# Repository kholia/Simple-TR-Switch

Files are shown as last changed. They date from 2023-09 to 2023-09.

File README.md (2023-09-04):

### Simple-TR-Switch

This is a non-RF-sensing, MCU PTT-controlled `Simple T/R Switch` with RX
Grounding feature which can be built for less than 2 dollars!

It was designed, and tested for https://github.com/kholia/Easy-Transceiver project.

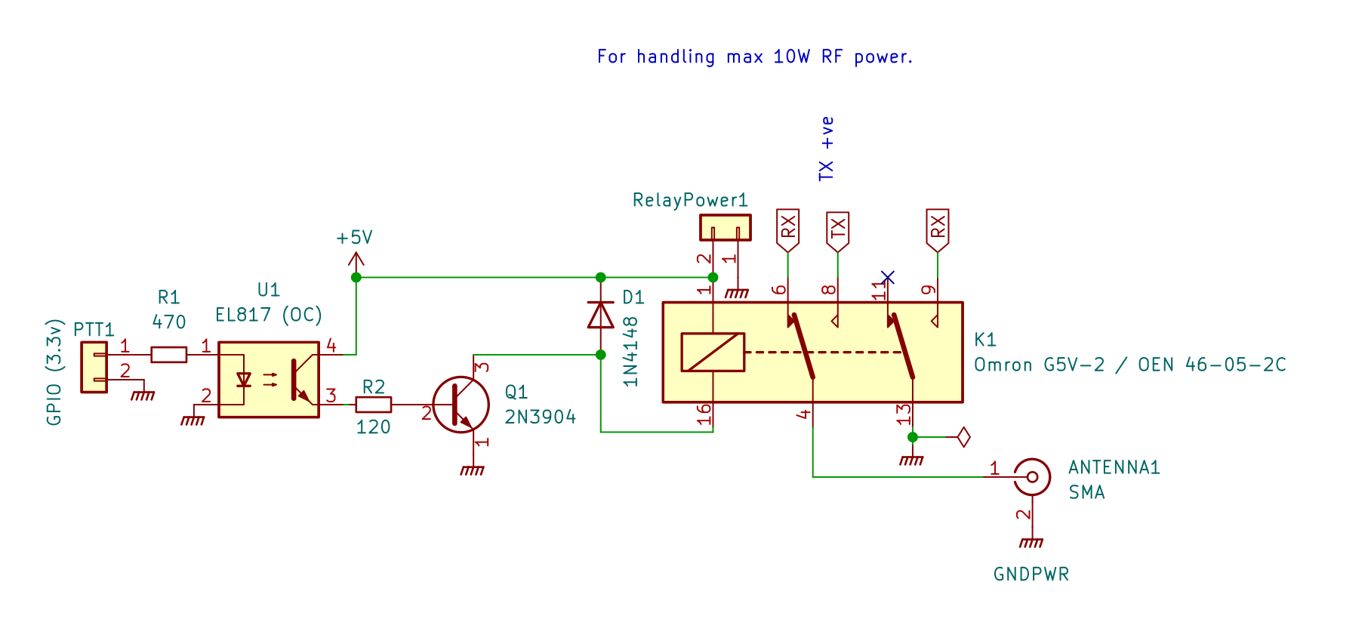
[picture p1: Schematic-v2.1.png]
Schematic

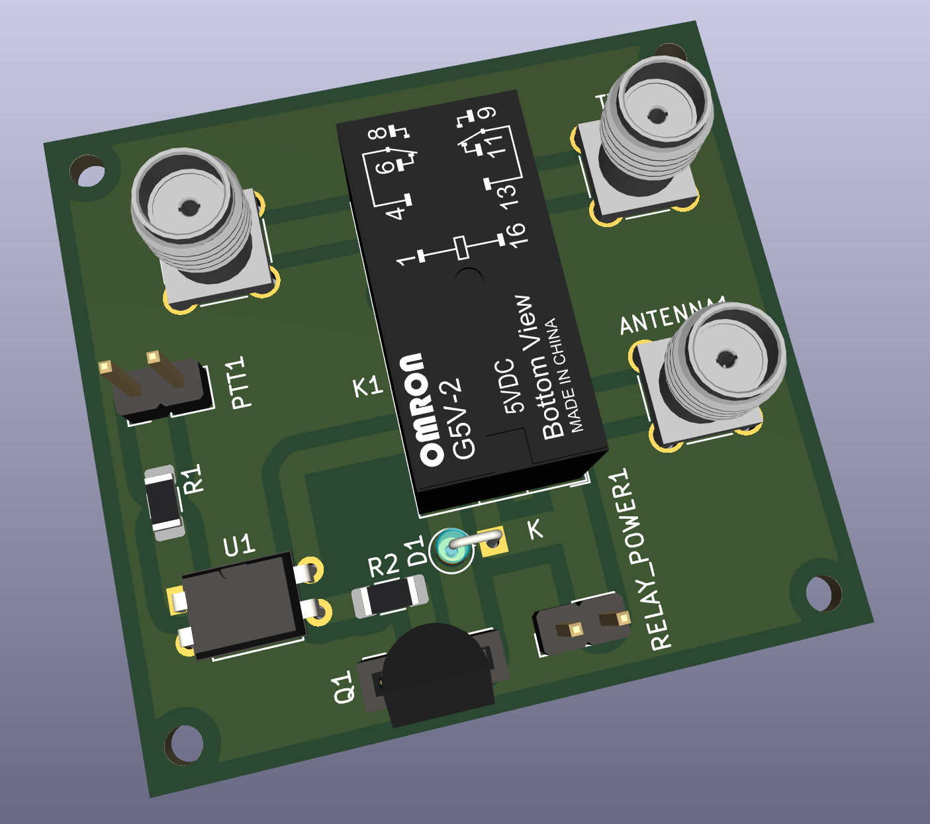
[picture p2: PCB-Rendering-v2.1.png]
PCB Rendering v2


#### Various approaches

TX power is 10W from IC-705 operating in FM mode.

- With a 2-channel relay as a T/R switch, when both RX Ground and Center are
  disconnected and left floating, a voltage of around ~2.2v is induced across
  RX connections which is unsafe for typical SDRs.

  ~2.2 Vpp is 10.93 dBm!

  https://www.random-science-tools.com/electronics/dBm-Watts-volts.htm

- With a 1-channel relay as a T/R switch which is switching the `Center`
  connection only, and with all Grounds (TX, RX, Antenna) shorted, a voltage of
  around ~1.66v is induced across RX connections which is theoretically safe
  for common SDRs.

- With a 2-channel relay as a T/R switch, with all Grounds (TX, RX, Antenna)
  shorted, with `Center` switching using Channel 1, and RX Center Grounding
  using Channel 2 during TX, a voltage of around ~500mV is induced across RX
  connections which should be fine for most common SDRs.

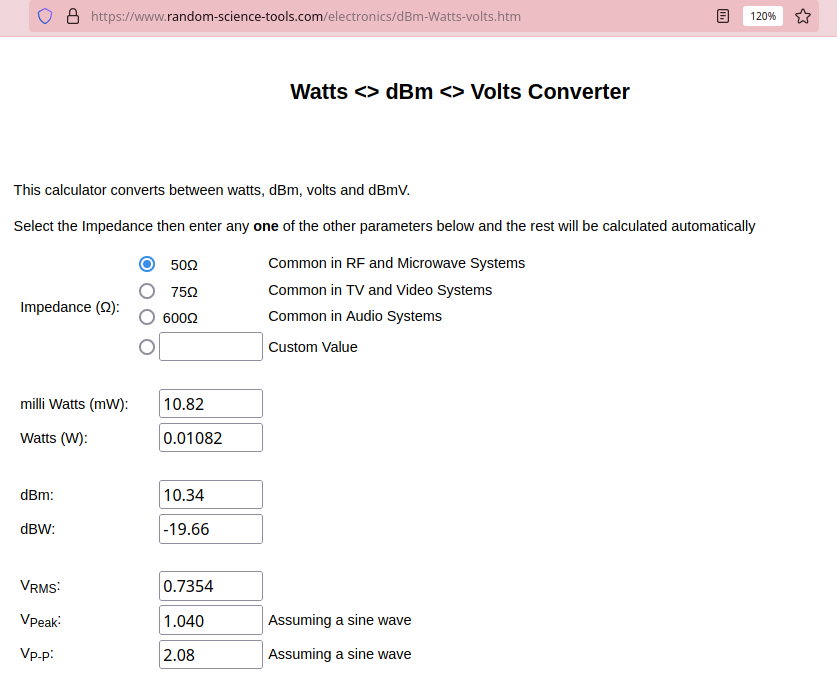
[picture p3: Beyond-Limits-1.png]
Beyond Limits


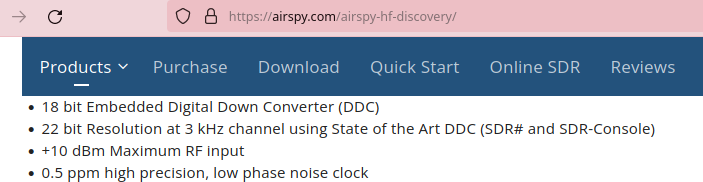
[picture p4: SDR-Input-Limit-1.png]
SDRs are sensitive devices


#### Comparisons

No external 12v power is needed unlike `Easy TR Switch` from https://www.qrpkits.com/ezseries.html.

The ~4000 INR `SDR Transceiver and Receiver Switch Antenna Sharer TR Switch Box
160 MHz` from Banggood doesn't work in `Automatic Mode` if there is
`Broadcast/SW Interference` in your area. The Banggood TR switch switches on
the RTX (red) and disconnects the SDR (RX) as soon as the antenna is connected
under `BCI` conditions, when operating in `Automatic Mode`.

#### BOM

- 5V 2A DPDT OEN MICRO RELAY 46-05-2C

  - https://etstore.in/index.php/product/oen-micro-relay-5v-dpdt-46-05-2c/
  - https://www.tomsonelectronics.com/products/oen-signal-relay-5v-dpdt

#### Added Protection

Here is another additional mechanism to protect sensitive SDRs.

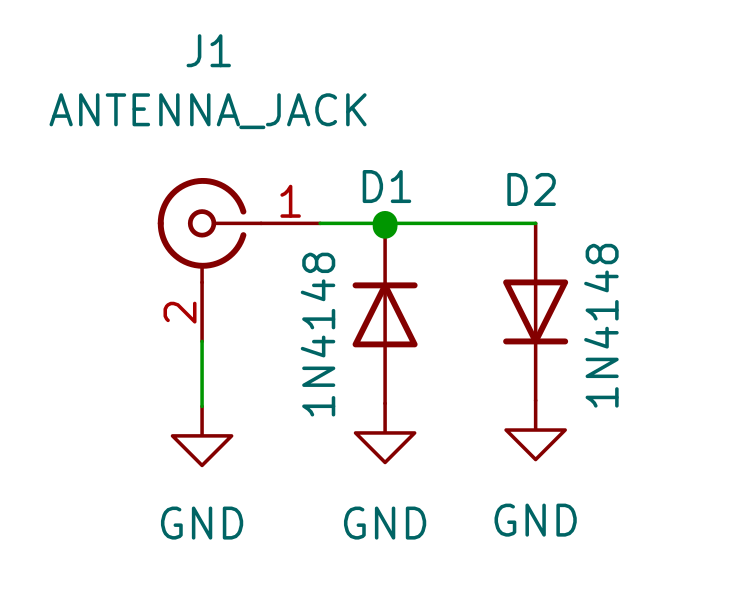
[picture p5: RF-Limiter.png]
RF Limiter


This is OK for HF (shortwave).

#### Alternate (but riskier) Option

Solid switching using BS170 could be another option.

The [info](./info) folder has more information on this.

#### Credits

Thanks to VU2ASH (Ashok Joshi), K.P.S. Kang, and LW1ECP (Daniel Alonso) for all
the help.

https://circuits-diy.com/optocoupler-relay-driver-with-pc817-2n3904/

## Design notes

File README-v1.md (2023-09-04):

### Simple-TR-Switch

This is a non-RF-sensing, MCU controlled `Simple T/R Switch` with RX Grounding
feature which can be built for less than 2 dollars!

It was designed, and tested for https://github.com/kholia/Easy-Transceiver project.

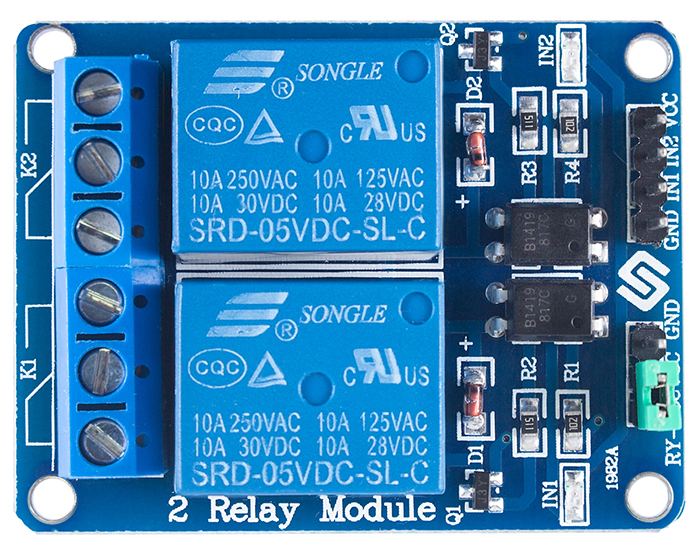
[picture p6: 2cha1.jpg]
Relay Module Looks

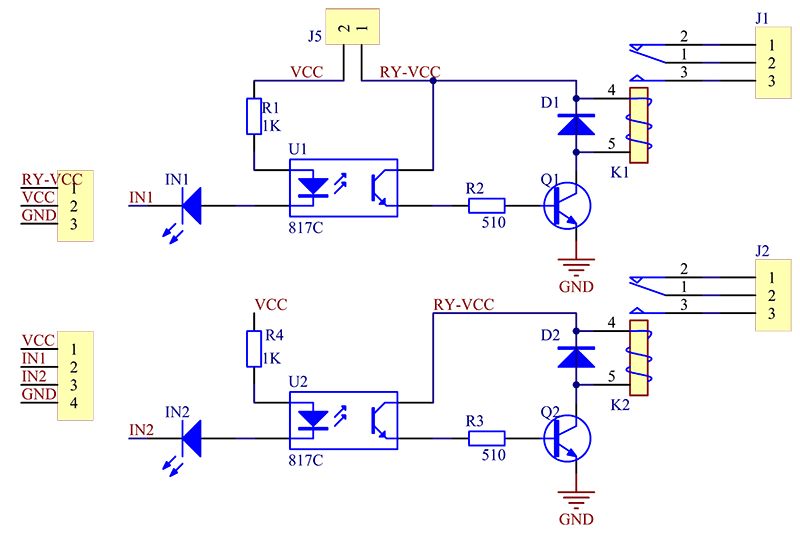
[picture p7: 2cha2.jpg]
Relay Module Schematic


#### Various approaches

TX power is 10W from IC-705 operating in FM mode.

- With a 2-channel relay as a T/R switch, when both RX Ground and Center are
  disconnected and left floating, a voltage of around ~2.2v is induced across
  RX connections which is unsafe for typical SDRs.

  ~2.2 Vpp is 10.93 dBm!

  https://www.random-science-tools.com/electronics/dBm-Watts-volts.htm

- With a 1-channel relay as a T/R switch which is switching the `Center`
  connection only, and with all Grounds (TX, RX, Antenna) shorted, a voltage of
  around ~1.66v is induced across RX connections which is theoretically safe
  for common SDRs.

- With a 2-channel relay as a T/R switch, with all Grounds (TX, RX, Antenna)
  shorted, with `Center` switching using Channel 1, and RX Center Grounding
  using Channel 2 during TX, a voltage of around ~500mV is induced across RX
  connections which should be fine for most common SDRs.

Beyond Limits

SDRs are sensitive devices

#### Comparisons

No external 12v power is needed unlike `Easy TR Switch` from https://www.qrpkits.com/ezseries.html.

The ~4000 INR `SDR Transceiver and Receiver Switch Antenna Sharer TR Switch Box
160 MHz` from Banggood doesn't work in `Automatic Mode` if there is
`Broadcast/SW Interference` in your area. The Banggood TR switch switches on
the RTX (red) and disconnects the SDR (RX) as soon as the antenna is connected
under `BCI` conditions, when operating in `Automatic Mode`.

#### Relay Connections

We use a 2-channel relay as a `T/R switch`.

Short all Grounds (TX, RX, Antenna).

```
Channel 1 (In 1):

- COM -> Antenna +ve
- NC -> RX +ve
- NO -> TX +ve
```

```
Channel 2 (In 2)

- COM -> Ground
- NC -> Not Connected
- NO -> RX +ve
```

In TX mode, turn on (i.e. make `NO` active) both Channel 1 and Channel 2, and
you should be good to go!

The following is a rough-schematic, only to show the connections involved.
Please use the relay module in practice. The flyback diodes across the relay
coils are important.

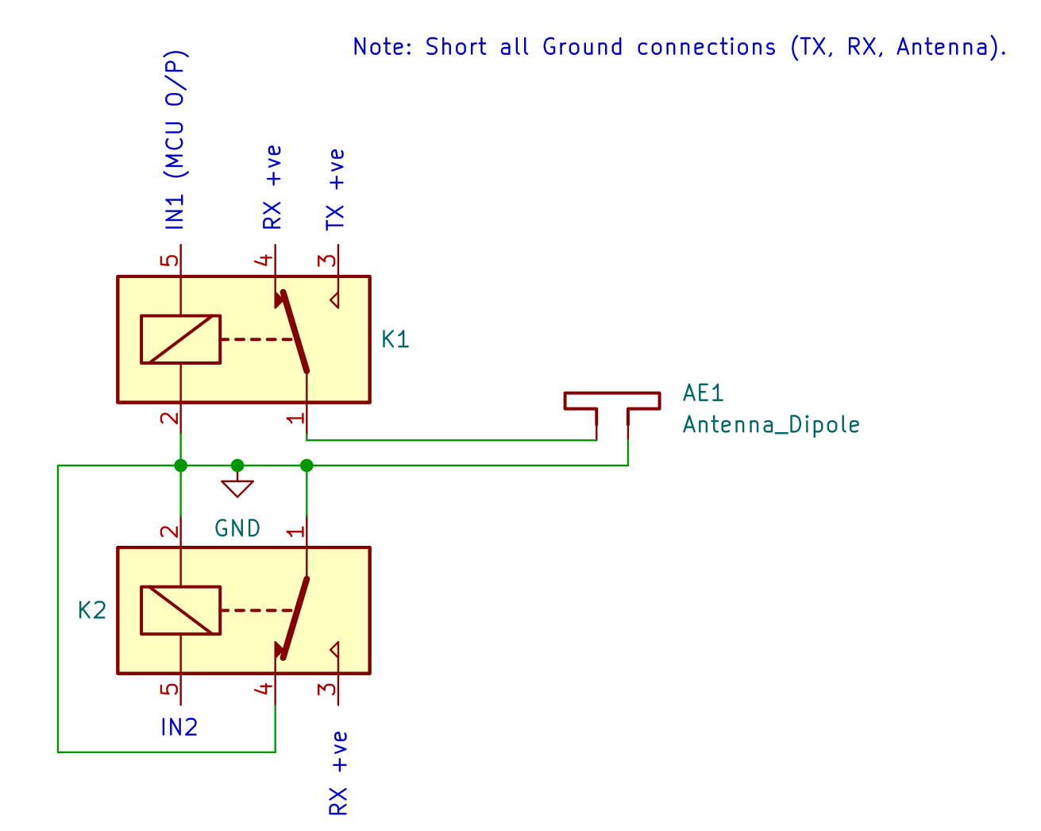
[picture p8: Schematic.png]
Schematic


#### Added Protection

Here is another additional mechanism to protect sensitive SDRs.

RF Limiter

This is OK for HF (shortwave).

#### Extender PCB

Use this for easy connections ;)

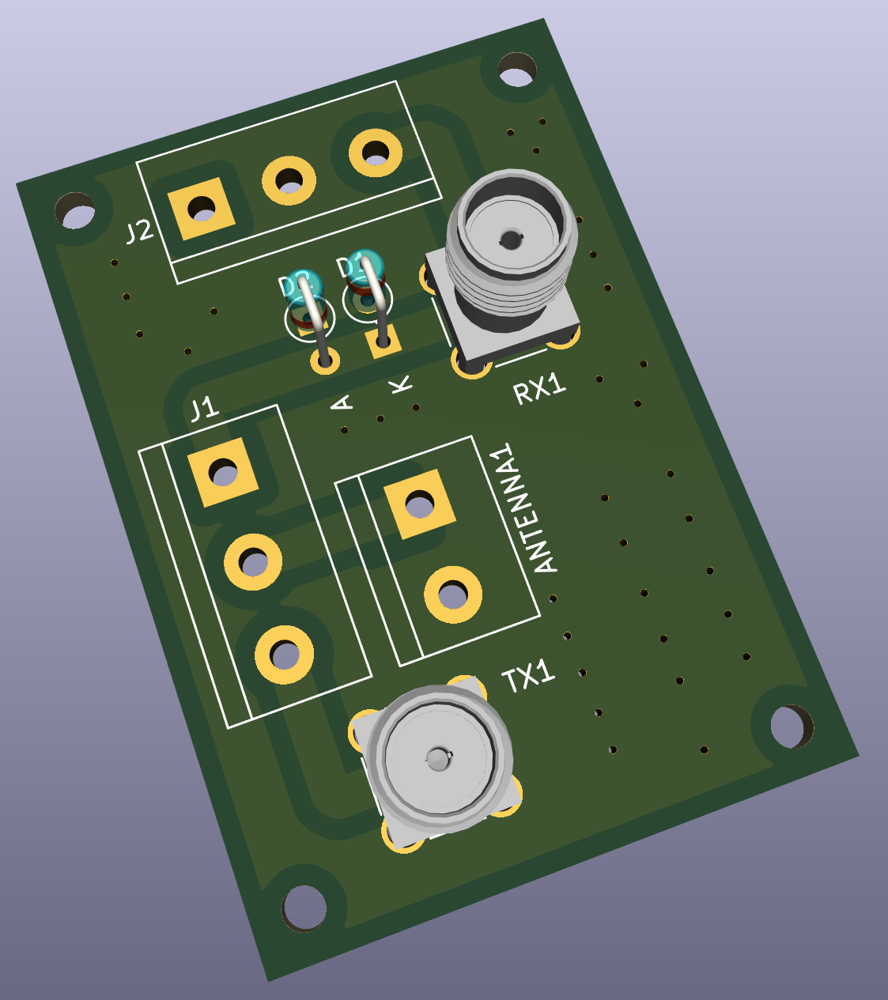
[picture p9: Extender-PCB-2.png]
Extender PCB


Use 0.5 sq. mm. wire with bootlace ferrules to ensure good contact. Keep the
wires short.

#### Alternate (but riskier) Option

Solid switching using BS170 could be another option.

The [info](./info) folder has more information on this.

#### Results (Feb-2022)

This TR switch affects SWR in the range of 0.10 to 0.15 for the worse, which is
quite acceptable in practice.

The TR switch is not affected by `BCI`.

After RX grounding, the RX line doesn't have any appreciable induced ("picked
up") voltage on it. The actual value couldn't be exactly determined due to
the measurement noise but it was less than 400mV as an rough approximation.
This was measured via an oscope using the differential probing technique
(`CH1 - CH2` in `MATH` mode).

The uSDX RX continued functioning just fine when connected to this TR switch,
after TX'ing 10W from IC-705 transceiver which was also connected to the same
TR switch.

#### BOM Sources

- https://www.electronicscomp.com/2-channel-5v-relay-module-with-optocoupler

#### References

- https://www.giangrandi.org/electronics/diode-clipper/diode-clipper.shtml

#### Credits

Thanks to VU2ASH (Ashok Joshi), K.P.S. Kang, and LW1ECP (Daniel Alonso) for all
the help.

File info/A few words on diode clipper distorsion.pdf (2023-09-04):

# A few words on diode clipper distorsion

## Introduction

I always had the habit of protecting the antenna input of many receiver circuits with a couple of back to back silicon diodes as visible in the picture below. This protects (within reason) a delicate circuit from unwanted strong signals applied to its input, such as switching on a nearby transmitter and having too much RF coupled to it or shorting to ground any static charge that may accumulate on an well insulated antenna. But I never spent time in investigating the additional distortion this circuit introduces, and this is the goal of this page.

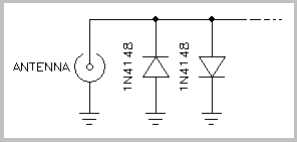
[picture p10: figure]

Typical antenna input circuit with protection diodes.

The basic idea of the diode clipper is that for signals with an amplitude within ±0.7 Vpeak (less than about +7 dBm over 50 Ω) the diodes are just open circuits and do not interfere; for higher amplitudes, the diodes clip the signal to about ±0.7 Vpeak limiting the maximum power that reaches the receiver at about
+10 dBm over 50 Ω, which the vast majority of receiver circuits can easily tolerate. If you wonder why I specified +7 dBm for unclipped signals and +10 dBm for clipped ones of the same peak to peak amplitude, it's because unclipped signals are supposed to have a nice sinusoidal shape; once clipped, they become more square and their RMS voltage is higher, explaining the 3 dB difference.

Now, this very simple diode model, where a diode is an open circuit for voltages below 0.7 V and clips at 0.7 V any higher level signal is just enough to estimate the limiting power, but is too simple to calculate the distortion on small (unclipped) signals. Diodes are non-linear devices often used in mixers and frequency multipliers, so they must introduce distortion. Now the question is: how much distortion? And is it acceptable?

## Circuit simulation

Now, the circuit that we want to simulate is basically a voltage divider with two diodes back to back as shown below:

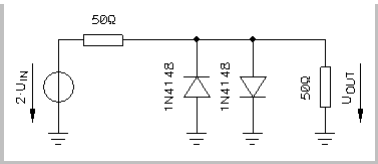
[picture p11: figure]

The circuit to simulate, the voltage source with its internal resistance is on the left, the two clipping diodes in the middle and the load is on the right.

The internal resistance of the generator (left) and the load resistance (right) are the two resistors of the divider. All impedances are supposed to be matched (both resistors are equal). The standard impedance of 50 Ω was selected because is the most common value for radio frequency circuits.

Very often, these two resistors are not "real" resistors, they are just how the source and load impedance look like, but they form indeed a voltage divider and the load voltage is half of the source voltage (when diodes don't clip). In practice, we don't have access to the true voltage source, and this 1:2 ratio is annoying. To avoid it, the source voltage is specified as 2·UIN, so that UIN is the voltage that appears on the load (UOUT) when no diodes are connected and we can compare what happens with and without the diodes without bothering with the 1:2 ratio.

The first attempt to simulate this circuit was done with a free SPICE simulator software, but rounding errors were too high for calculating any harmonic distortion or third order intercept point: it generated a strange and unrealistic noise floor
60 dB below the main signal. So a different way of simulation had to be found.

Finally, since the circuit is quite simple, I decided to directly calculate the output voltage in the old "pencil and paper" way. But for this, a good diode model is required.

The Shockley ideal diode equation is used here because it allows calculating precisely what happens for small and large signals. It relates the diode (forward) current ID as a function of diode (forward) voltage U.

It's an exponential function and depends on U, but also on three parameters that we consider constant for this simulation. The reverse bias saturation current IS and the emission coefficient n depend on the particular diode we want to simulate. Here, to simulate the famous 1N4148, we chose IS = 4.352 nA and n = 1.906 (these values are the ones specified by NXP in their SPICE model). Here we used a thermal voltage UT = 26 mV corresponding to a (room) temperature of 300 K and taken as constant. Small thermal variations are out of scope for this discussion.

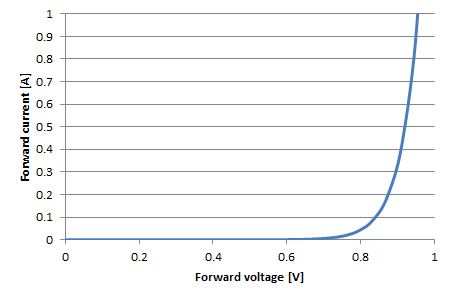
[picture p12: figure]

Diode forward current as a function of diode forward voltage of a 1N4148 according to the Shockley equation.

If we plot this equation, we get the above curve: it corresponds well to what we expect from a general purpose silicon diode such as the 1N4148.

The circuit to calculate can is completely described by the following two equations that are just the application of Kirchhoff laws:

;

ID(UOUT) is, of course, the Shockley equation described before. By combining and rearranging these two equations, we obtain the following:

Now, the above equation gives UIN(UOUT) while we are looking for UOUT(UIN). But solving for UOUT cannot be done analytically because of the exponential in the Shockley equation (or, if it can, I couldn't do it). So, I ended up in solving it numerically, using MS Excel, its numerical solver and some macros; it's not very elegant and is terribly slow, but finds a solution with the required accuracy and was readily available.

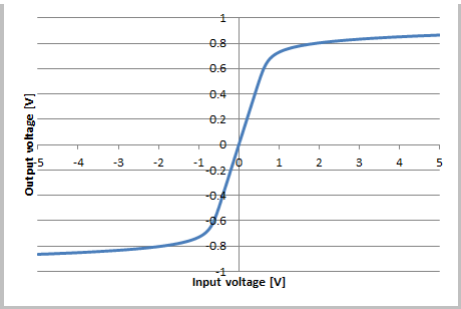
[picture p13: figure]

Transfer function of the diode clipper.

The calculated transfer function is visible in the above plot. As expected, it's about linear between ±0.6 V, for higher amplitudes se signal is compressed around ±0.7-0.8 V. This is a smooth curve and has no sharp angles.

Please remark that in this simulation, only the forward polarized diode is taken into account. The other diode is supposed to conduct no current: this greatly simplifies the calculation.

## Determining harmonics

Now that we have a nice model for the diode clipper, we can feed it with some sinusoidal input signal to calculate with good accuracy the clamped signal at the output. Then, with an FFT, we can precisely analyze the harmonic content of the output signal. By repeating this process for different amplitudes, it is possible to have an idea of the maximum signal that will go through the clipper undistorted (or with an acceptable distortion).

Several amplitudes have been used for this simulation: –100 dBm, –80 dBm,
–60 dBm, –50 dBm, –40 dBm, –30 dBm, –20 dBm, –10 dBm, –5 dBm, 0 dBm,
+5 dBm, +10 dBm, +15 dBm, +20 dBm, +25 dBm and +30 dBm. The typical signals that can be found on a receiver antenna connector range from –140 dBm to –30 dBm, –73 dBm being the standard S9 signal, (https://www.giangrandi.org/electronics/radio/smeter.shtml) already considered strong. There is no need to simulate signals weaker than –100 dBm because already at –100 dBm distortion is so low that cannot be calculated. On the other hand, signals up to
+30 dBm have been simulated to see what happens when the clipper really does its job.

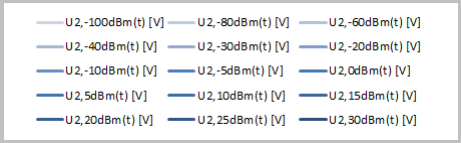
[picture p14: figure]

Legend for the signals plotted in the following two figures.

In the figure below, all input signals are displayed. With a linear scale, only the strongest ones are clearly visible.

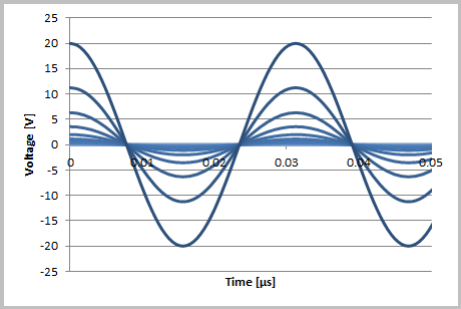
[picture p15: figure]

Input signals ranging from –100 dBm to +30 dBm.

The figure below shows how the signals look like after the clipper. Again plotted on a linear scale, the compression is clearly visible: the strongest signals (that exceeded several Volts before the clipper) are now within ±1 V and have a "square wave" appearance, while the weak signals go through undistorted and keep their sinusoidal shape.

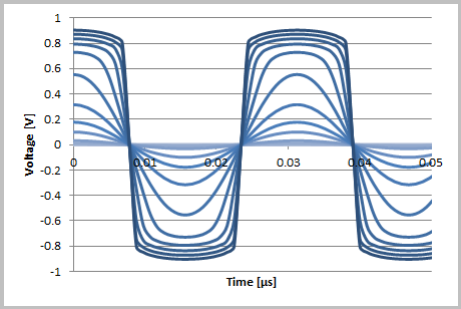
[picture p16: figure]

The same signals as in the previous image after clipping.

To perform reliable FFT on this numerical model, a few tricks are necessary: first, the FFT algorithm works only with a sampling period containing a number of samples which is an integer power or 2; here we used 1024 samples (= 2¹⁰). Than the signal to analyze must have an integer number of cycles in the sampling period, otherwise spurious signals will appear, polluting the result. Since the model is not frequency dependent, we arbitrarily chosen a sampling frequency of 1024 MHz, a sampling period of 1 μs (1024 samples, one every 0.977 ns), and a test signal of

32 MHz. With these conditions, it has exactly 32 full cycles in the 1024 samples. This gives an FFT resolution of 1 MHz, which is also handy.

Again, the simulation is calculated with MS Excel, its built in FFT function and some macros. As before, not elegant and slow but provides accurate results.

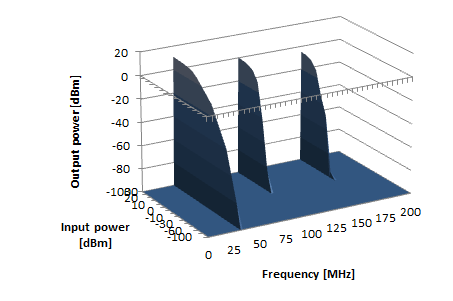
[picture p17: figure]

Waterfall plot of the FFT analysis of the diode clipper using a 32 MHz signal.

The result of the FFT is displayed in the above 3D plot. As one can see, for input signals below 0 dBm, the harmonic content is very low, but for stronger signals distortion rapidly appears with stronger and stronger harmonics.

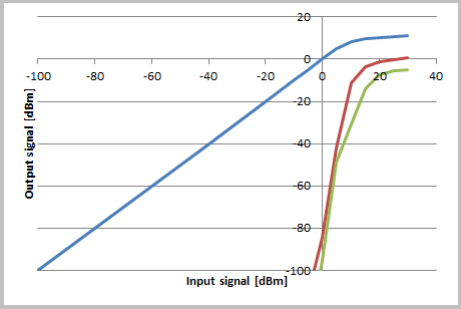
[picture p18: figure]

Frequency domain transfer function of the diode clipper. Blue: fundamental frequency, red: third harmonic, green: fifth harmonic.

Another way to look at it is in the frequency domain transfer function displayed above. We note that for low amplitudes, say below a few dBm, the clipper is linear and has a slope of 1 (the same signal goes through undisturbed). Distortion (harmonics) is almost non-existent in this region. At about 0 dBm third and fifth harmonics start to appear and grow very rapidly. At the same time, the transfer function shows a knee and even for strong input signals, the output does not exceed +10 dBm, as expected from a clipper.

## Determining IP3

Third order intercept point (IP3) is closely related (and very similar) to harmonic distortion. To evaluate its value the same analysis as before has been repeated using a superposition of two signals at two different frequencies, but with the same amplitude. The result has been analyzed in the same way. Since both signals must have an integer number of cycles in the 1024 samples, the frequencies of 16 and 24 MHz have been arbitrarily selected. They have respectively 16 and 24 cycles. Since the model is frequency independent, there is no reason to use frequencies very close to each other as one would use in a real life test.

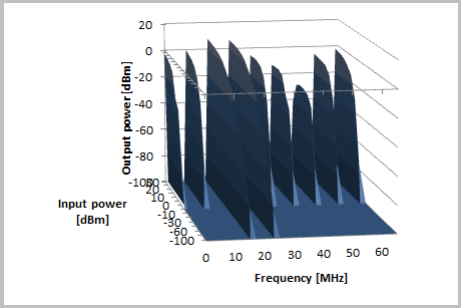
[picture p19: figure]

Waterfall plot of the FFT analysis of the diode clipper using two signals at 16 and 24 MHz.

The 3D waterfall graph (above) is now more crowded but very similar as before. One can easily see both input signals at 16 and 24 MHz and the third order intermodulation products appearing at 8 and 32 MHz for input signals stronger than about 0 dBm. Other higher order intermodulation products are visible as well.

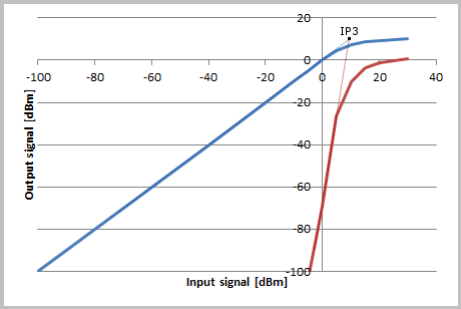
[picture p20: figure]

Frequency domain transfer function of the diode clipper. Blue: fundamental frequency, red: third order intermodulation products.

On the above frequency domain transfer function, the third order intercept point (IP3) is clearly visible and is at +10 dBm. Since the slope of the transfer function is 1 (same amplitude for input and output signals), there is no difference between input and output third order intercept points (IIP3 and OIP3 respectively): they both are +10 dBm.

## Some measurements

In order to verify what has been calculated before, some real measurements are a must. Here, a 1 MHz sinusoidal signal was used. Real life is not frequency independent and a "low" frequency such as 1 MHz allows neglecting the length of diode leads and the stray capacitance introduced by the diodes themselves. The two diodes are, of course, a pair of 1N4148. The result is shown in the waterfall plot below:

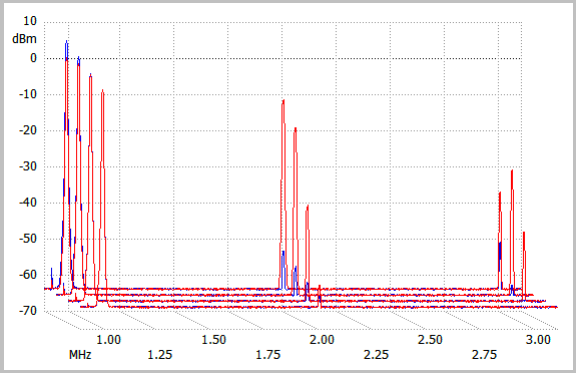
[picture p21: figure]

Measured spectra of a 1 MHz signal at four different amplitudes: +4 dBm, +1 dBm, –2 dBm and –5 dBm. Blue: no diodes, just the input signal. Red: diodes connected.

As one can see, for amplitudes below –5 dBm, no harmonics can be observed, but as the amplitude rises, as expected, harmonics appear and grow rapidly. This corresponds to the expectations.

But there are differences with the previous theoretical model: one is that in practice the input signal is not perfectly a pure sine wave and has already some harmonic content (blue traces). As expected, these harmonics are increased by the clipping action of the circuit.

Another difference is a strong presence of even harmonics, while in our theoretical model, only odd harmonics appear. I suspect that is due the two diodes not being identical and not clipping the signal symmetrically, but I didn't investigate this any further.

## Other considerations

One important question is: what is the maximum power that we can feed to the clipper without damaging it? According to the NXP datasheet, a 1N4148 diode can withstand a continuous DC current of 200 mA and can dissipate maximum of
500 mW. Let's first calculate what is the power dissipated by the diode at its maximum current: 200 mA · 0.7 V = 140 mW. Since this is lower than its maximum power rating of 500 mW, we will use 200 mA in our calculation, otherwise we would have to use a lower current. When the diodes are clipping, the load impedance is no longer 50 Ω because of the diodes somehow shorting it to ground. Since current in the diodes is much larger than the current in the load, we will neglect the latter and consider that all current is flowing through the diodes. When a power source delivers half of the diode maximum current on a 50 Ω load, here 100 mA, it delivers (100 mA)² · 50 Ω = 0.5 W of power. When the same source is connected to our clipper it will no longer be matched to 50 Ω because of the diodes appearing like a short circuit: the current will tend to double (our maximum
200 mA) and the power will drop significantly because voltage is now limited around 0.7 V. Therefore we can say that the maximum safe power source than we can connect is around 0.5 W (27 dBm).

Higher ratings diodes will certainly resist a higher power, but will probably have the disadvantage of introducing more stray capacitance. Each 1N4148 will add
4 pF: depending on the frequency this may or may not be a problem, and may require compensation. For example, if there is a low-pass filter after the clipper, is easy to compensate for the extra stray capacitance, just by reducing the parallel input capacitor.

Diodes often (but not always) show a nice feature: when too much power is applied, they will of course blow up; but after blowing up, they become a short circuit. In this case, even if the diodes are dead, they are still protecting the rest of the circuit. So, even if an overload does occur, there are still good chances that only two diodes of the clipper are faulty.

Not every diode is suitable for this circuit: fast diodes are needed. 1N4148 have a switching time of 4 ns and are good up to a few dozen MHz; for higher frequencies, faster diodes should be used.

## Conclusion

The effect of two back to back diodes in parallel with a receiver antenna connector has been analyzed. Their effect is negligible for weak signals, say below –20 dBm, it becomes observable around 0 dBm and the clipping action limits the maximum power around +10 dBm. The IP3 has been calculated to be +10 dBm.

If this is acceptable or not depends on the application. A diode clipper will certainly ruin the performance of a professional top of the line +30 dBm or more IP3 receiver, but can accepted in many other cases: when the receiver is just good but not a top performer, or when the antenna is located and designed in such a way that it doesn't pick up strong signals, or when a narrowband filter prevents strong signals to reach the clipper.

## Bibliography and further reading

[1] Dr. F. Rahali, Prof. M. Declercq. Électronique I, partie 2: dispositifs à semiconducteurs. École Polytechnique Fédérale de Lausanne, 1996, chapitre 8.
Home (https://www.giangrandi.org/index.shtml) | Electronics (https://www.giangrandi.org/electronics/electronics.shtml) | Page hits:
| | 017599

Created:
09.2014

Last update:
09.2014

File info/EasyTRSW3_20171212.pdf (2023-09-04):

# Pacific Antenna Easy TR Switch Kit

## Kit Description

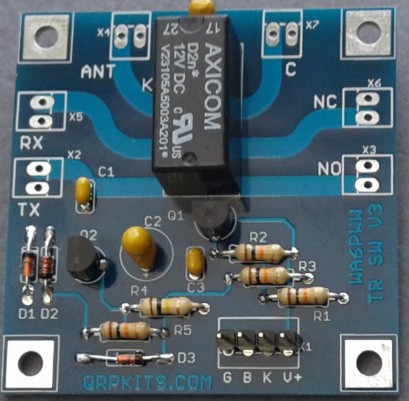
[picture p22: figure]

The Easy TR Switch is an RF sensing circuit with a double pole double throw relay that can be used to automatically switch an antenna between a separate receiver and transmitter.

It also has a second switched pair of inputs and outputs that can be used for other switching applications such as muting or switching an audio channel or even to switch a remote amplifier or pre-amplifier.

Manual operation is achieved through use of control inputs to disable RF switching and to key the relay.

## Features and Specifications

Provides automated or manual switching
Two independent sets of inputs and outputs
Automatic Rf sensing requiring as little as 50mW of RF for switching Frequency range of 160-6M
Power handling of up to 125 Watts
All on a 2 by 2 inch circuit board.

## Support

PACIFIC ANTENNA
QRP KITS.COM
qrpkits.com@gmail.com
Easy TR Switch V3 20171212 | 1

## Recommended Tools

□ Temperature Controlled Soldering Station with small tip or a 15-35 watt soldering iron with small tip. □ Solder 60/40 or 63/37 Tin-Lead
□ Small Diagonal Cutters
□ Small Needle Nose Pliers
□ Pencil, Pen, and/or Highlighter □ BRIGHT work light

## Optional

□ Magnifying headpiece or lighted magnifying glass. □ Multi-meter
□ Solder Sucker or Solder Wick
□ Knife or Wire Stripper
□ Cookie Sheet to build in and keep parts from jumping onto the floor.

## Construction Techniques

□ Please take time to inventory the parts before starting. Report any shortages to QRPKITS.com (In many cases it may be faster and cheaper to pull a replacement from your parts supply, but please let us know if we missed something.)

□ Pre-sorting the resistors and capacitors can speed up the assembly and reduce mistakes.

□ There is no need to print out the whole assembly manual unless you want a copy. Print the Parts List and Schematic (last two pages) then view the rest of the manual on a computer, laptop, or tablet. The Parts List has columns for inventory and construction.

□ You can insert several parts at a time onto the board. When you insert a part bend the leads over slightly to hold the part in place, then solder all at the same time. Clip the leads flush.

□ Most parts should be mounted as close to the board as possible. Transistors should be mounted about 1/8” above the board. Solder one lead on ICs or IC sockets and then check to make sure the component is flush before soldering the remaining leads.

□ Use a Temperature Controlled Soldering Station with small tip or 15-35 watt soldering iron with small tip. Conical or very small screw driver tips are best.

□ DO NOT use a large soldering iron or soldering gun.

□ If you are a beginner, new to soldering, there are a number of resources on the web to help you get on the right track soldering like a pro. Google Soldering Techniques.

Easy TR Switch V3 20171212 | 2

## TR Switch V3 Parts List

Qty Value | Component | Description
4 | 10K | R1, R2, R3, R5 | Resistor, 1/4W, Brown-Black-Orange-Gold
1 | 100K | R4 | Resistor, 1/4W, Brown-Black-Yellow-Gold
2 | 1N4148 | D1, D2 | Diode, glass body (Check labels with magnifier)
1 | 1N5240 | D3 | Zener diode, 10V, glass body, (Check label with magnifier)
1 | 47pF | C1 | Monolythic Capacitor, marked 47 or 470. (0.1” lead spacing)
1 | 22pF | C1 alternate | Monolythic Capacitor, marked 22 or 220. (0.1” lead spacing)
2 | 0.1uF | C3, C4 | Monolythic Capacitor, marked 104. (0.1” lead spacing)
1 | 4.7uF | C2 | Tantalum polarized capacitor, marked 4u7 or 475
1 | 2N3906 | Q1 | PNP Transistor
1 | BS170 | Q2 | N-Channel MosFet
1 | Relay | K1 | Axicom V23105 12V relay
1 | PCB | PCB | Circuit Board labeled TR SW V3

Typical Parts Appearance

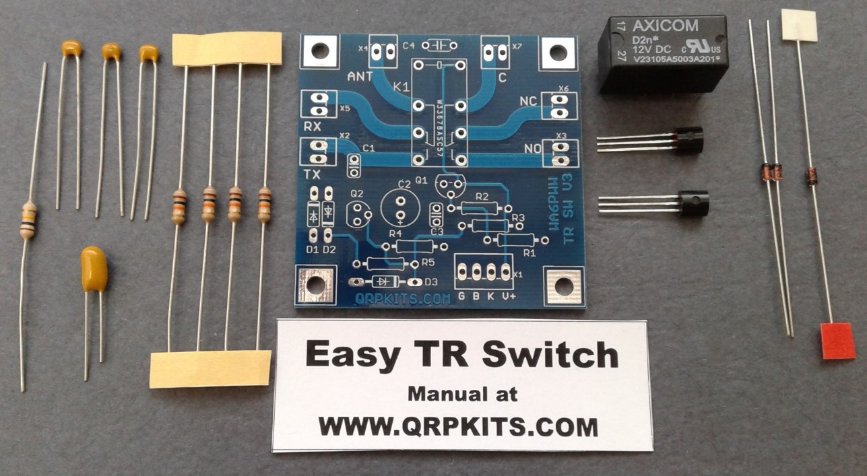
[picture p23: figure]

Note: Some parts may vary in appearance from those shown here due to source changes.

Easy TR Switch V3 20171212 | 3

Board Layout

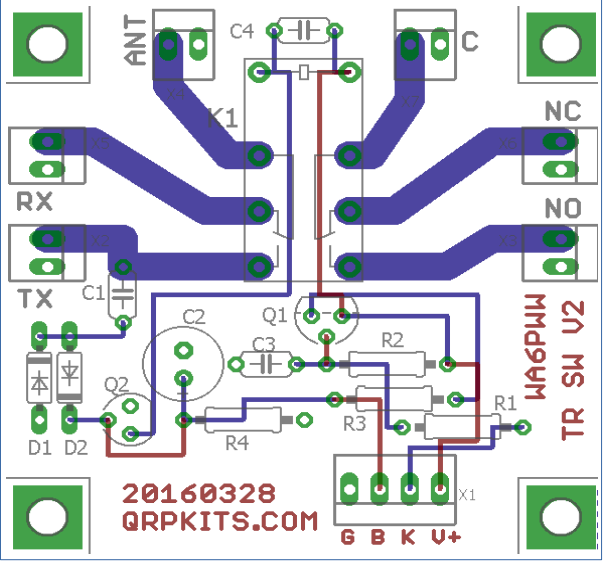
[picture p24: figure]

Note: Pin 1 of X1 is the pad closest to the X1 Label (on the right above) and is the connection point for 12V power. The leftmost pin (4) is ground connection.

Install the following components on the PC board.
Resistors
R1 | 10K Ohm, 1/4W, Brown-Black-Orange-Gold
R2 | 10K Ohm, 1/4W, Brown-Black-Orange-Gold
R3 | 10K Ohm, 1/4W, Brown-Black-Orange-Gold
R5 | 10K Ohm, 1/4W, Brown-Black-Orange-Gold
R4 | 100K Ohm, 1/4W, Brown-Black-Yellow-Gold

Capacitors
C1 | 47pF Note: a 22pF is also included and is recommended for high power (>50W) use.
C2 | 4.7uf Tantalum Note: align + side lead with + pad on board outline
C3 | 0.1uF monolythic ceramic, marked 104
C4 | 0.1uF monolythic ceramic, marked 104

Transistors and diodes
Q1 | 2N3906 (align flat to board outline with center pin away from flat)
Q2 | BS170 (align flat to board outline with center pin away from flat)
D1 | 1N4148 (align band to board outline) Note: confirm labels on diodes with magnifier
D2 | 1N4148 (align band to board outline) Note: confirm labels on diodes with magnifier
D3 | 1N5240 (align band to board outline), Note: confirm labels on diodes with magnifier

Misc parts
K1 | Axicom V23105 Relay, (only fits one way due to pin configuration)
Header | Pin header that can be used for connection if wires are not to be directly soldered
Easy TR Switch V3 20171212 | 4

## Operation

The TR switch provides switching between two separate sets of contacts to two separate output/input pairs.
It will sense RF input on the TX inputs and switch at approximately 50mW of RF and above and can be used over a frequency range of 160-6M and up to 125 Watts of RF under matched conditions.
The switch can be bypassed by grounding pin 3 (Bypass) of the control inputs (X1). This will prevent the switch from engaging either in manual or automatic, RF sensed mode.
For testing, or for manual switching from an external control, operation of the relay can be accomplished by grounding pin 2 (Key).
12V DC power should be connected at connector SV1 with V+ to pin 1 (marked “V+”) and ground to pin 4 (marked “G”)
Choice of C1:
Capacitor C1 senses the RF signal and feeds the signal to Q2 to control switching.
The 47pF capacitor supplied for C1 should work over most conditions and is recommended for most applications. An extra 22pF capacitor is also included and is recommended if power levels used will always be above 50W.
If automated switching is not reliable on certain frequencies, or at certain power levels, the value of C1 may need to be adjusted.
In general, increase C1 for lower frequency and/or lower power operation and decrease it for high frequency and or high power use.

## Board Connections

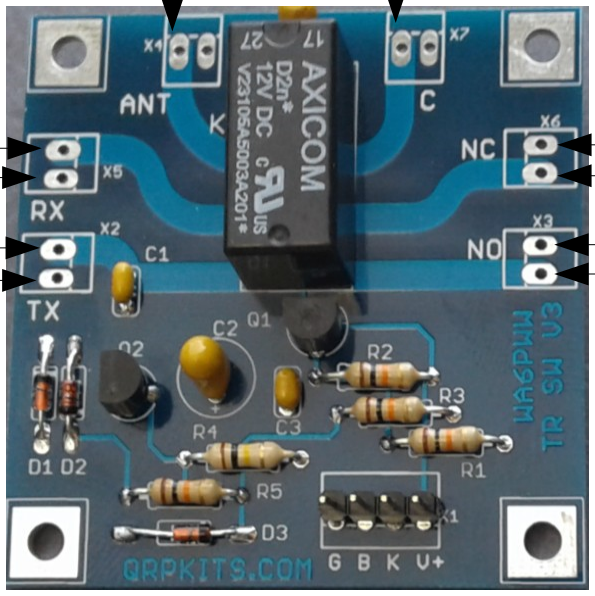
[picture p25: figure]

The Antenna, RX and TX as well as the second switched pair (C, NC and NO) are as shown above.

Easy TR Switch V3 20171212 | 5

RX
GND

TX
GND

GND
Normally Closed

GND
Normally Open
Antenna | Aux.

For the pads marked RX, TX, NC and NO, the connection is to the upper pad and the lower pads are connected to ground on the board as shown above.

For antenna switching between a receiver and Transmitter, you will only need to use the ANT, RX and TX connections.

The Auxiliary contact set can be utilized to mute audio of a receiver by switching its output to a resistor during transmit instead of the speaker or headphones.

This would be accomplished by connecting the audio to the Aux input and connecting a speaker to the normally closed (NC) output and a 10 ohm or so resistor from the normally open output to ground.

If the TR switch is embedded into another system, jumper wires can be used to the appropriate pads for signals, power and control lines (if needed).

To connect to a BNC or other external RF type connectors, the center will go to the pads as shown below and the ground is the adjacent pad.

You can see the pads with traces and connected to ground by looking at the back of the board. As a guide, the trace locations are shown in the drawing below.

The additional switched contacts (if used), are connected in the same manner.

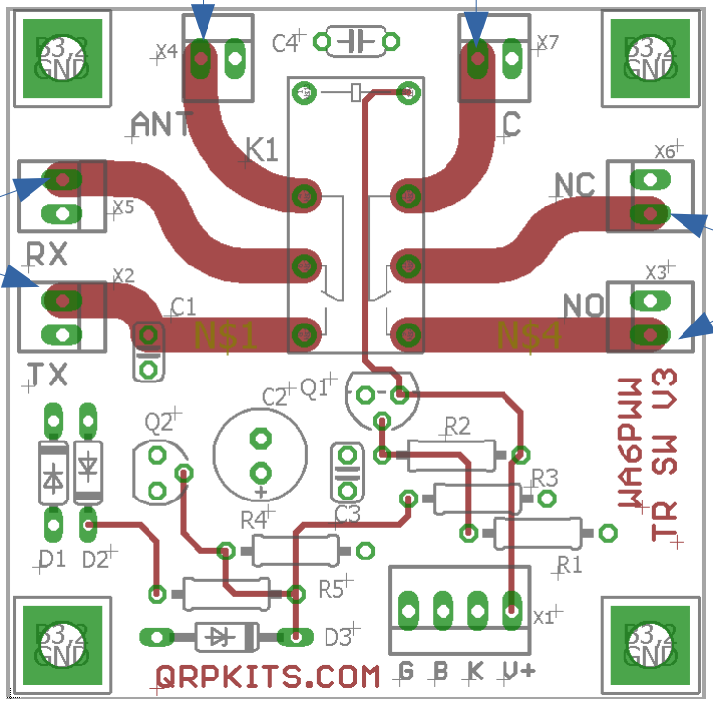
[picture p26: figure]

Easy TR Switch V3 20171212 | 6

Connect
center of
BNC here

Connect
center of
BNC here

Connect
center of
BNC here

Connect
center of
BNC here

X1: Control and Power input
Pin 1: V+; Pin next to X1 label on board, connects to a 12 Volt supply to power the TR switch. Pin 2: K; External keying control line. Ground this pin to key the TR switch manually.
Pin 3: B: Bypass control line. Ground to disable switching.
Pin 4: Ground for power, control and key signals

## Troubleshooting

The Easy TR switch is intended to be easy to assemble and should operate without any problems. However, if it fails to operate, there are a few things to check:

Check the board for cold solder joints, these will appear rough rather than shiny. If in doubt, reheat connections to ensure a good connection.

Check for any solder bridges or solder whiskers that may short between adjacent pads

Verify correct location and orientation of the diodes D1 and D2 as well as the transistors Q1 and Q2. They should be oriented as shown on the PC board outlines.

Verify that power and ground are connected to Pads 1 and 4 of X1.

Test by connecting Pad 2 of X1 to ground with 12 power applied to Pin 1. You should be able to hear the relay click. If not, recheck components and solder connections as indicated above.

When applying RF to the TX input, with an antenna or dummy load connected to the output you should hear the relay click.

Capacitor C1 is part of the RF sensing circuit that controls the automatic TR switching.

The kit is supplied with a 22pF capacitor for C1 and for most applications, this will work well. In general, a larger value capacitor (47 or 100pF) may improve switching at low power and low frequencies (<1Mhz).

If you still experience problems, or have any questions, please contact us at qrpkits.com@gmail.com and we will be happy to assist you.

Easy TR Switch V3 20171212 | 7
4 | 3 | 2 | 1
G | B | K V+

X1

## Schematic

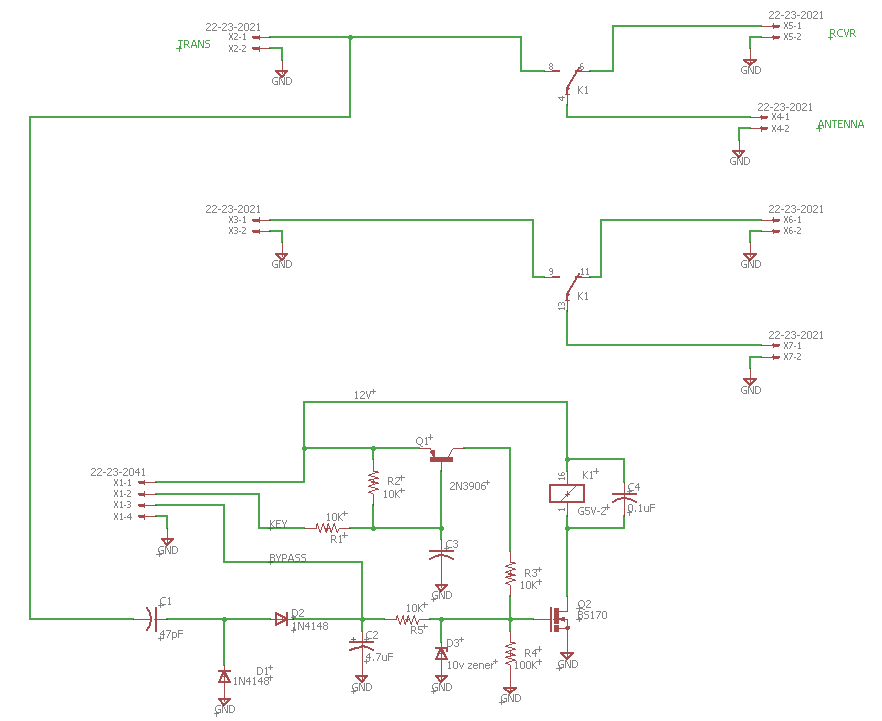
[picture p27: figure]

Easy TR Switch V3 20171212 | 8

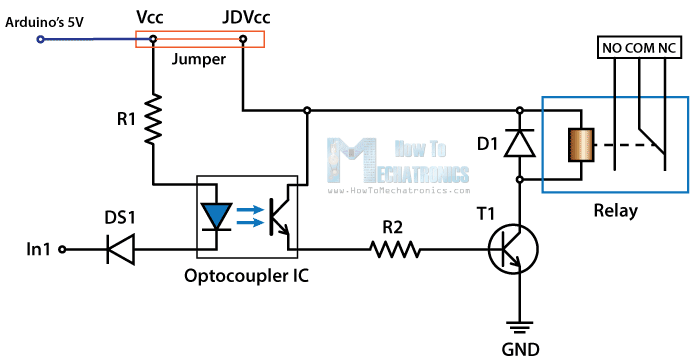
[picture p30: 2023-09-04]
info/HL-52S-Relay-Module-Circuit-Schematics.png

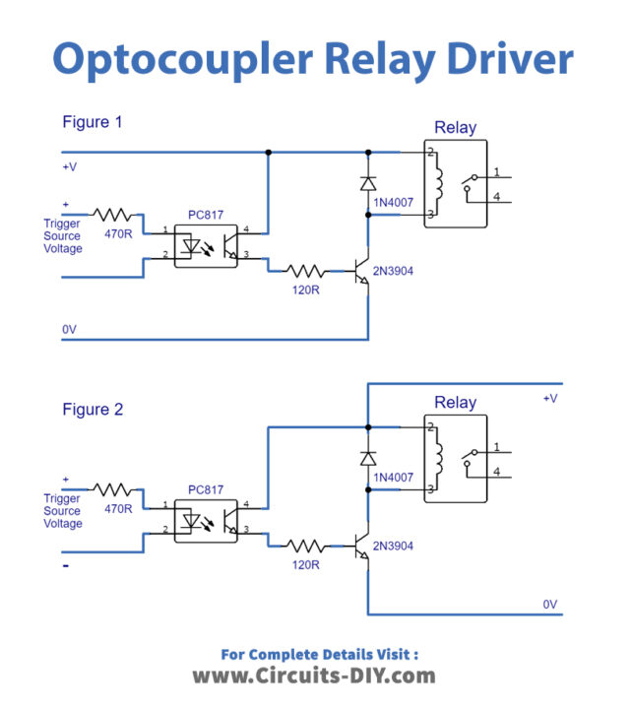
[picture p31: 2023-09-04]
info/Optocoupler-Relay-Driver-Circuit-Diagram-Schematic-641x720.jpg

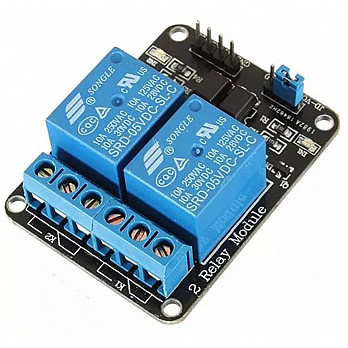
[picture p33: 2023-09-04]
dual-channel-relay.jpeg

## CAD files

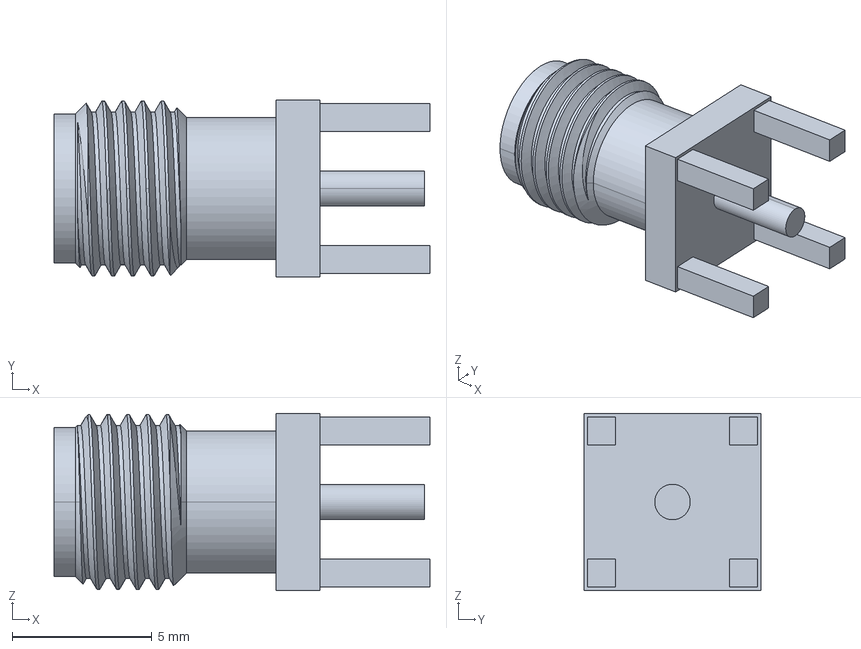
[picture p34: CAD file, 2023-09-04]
extender-pcb/models/901-144.stp
13.5 x 6.35 x 6.35 mm

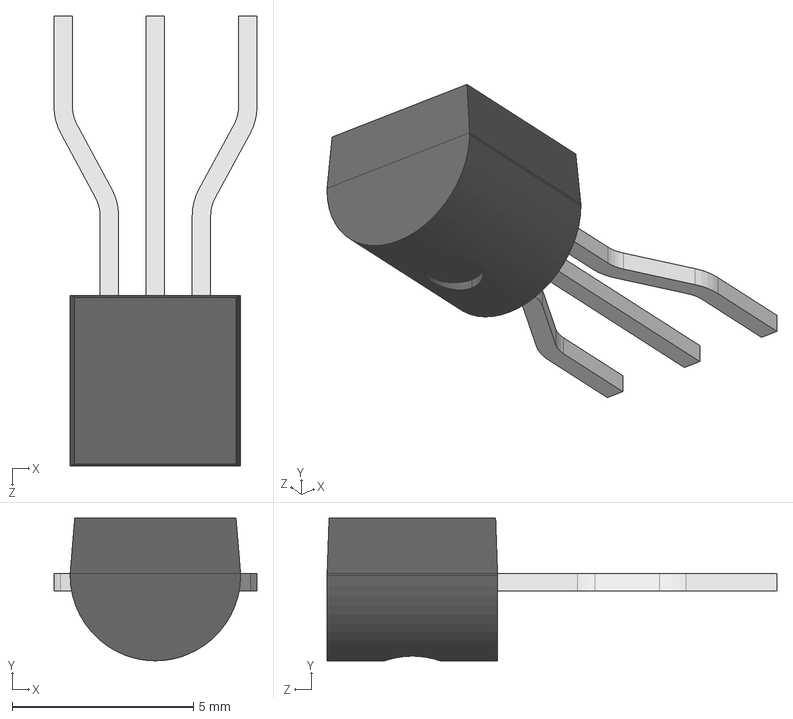
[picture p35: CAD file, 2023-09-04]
v3/models/User Library-TO-92-2_54-line.STEP
5.60 x 3.93 x 12.4 mm
User Library-TO-92 Version2_TO-92 Part1
User Library-TO-92 Version2_TO-92 Part3
User Library-TO-92 Version2_TO-92 Part4
User Library-TO-92 Version2_TO-92 Part5

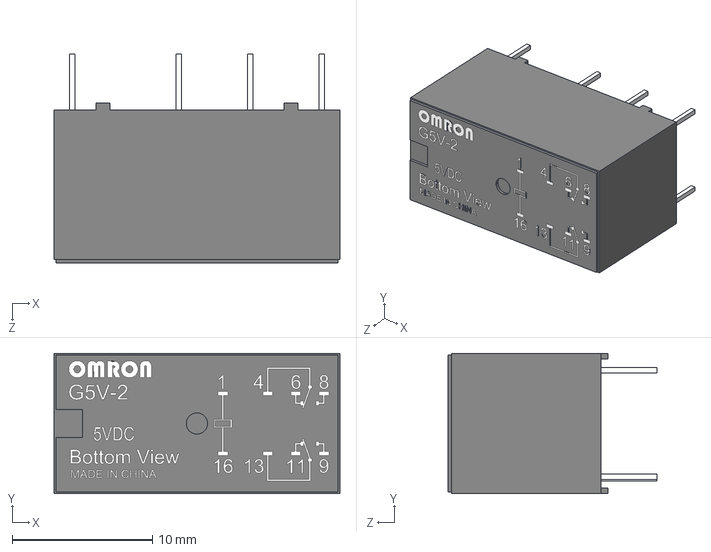
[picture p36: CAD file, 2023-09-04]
v3/models/User Library-OMRON G5V-2.STEP
20.4 x 10.0 x 14.9 mm

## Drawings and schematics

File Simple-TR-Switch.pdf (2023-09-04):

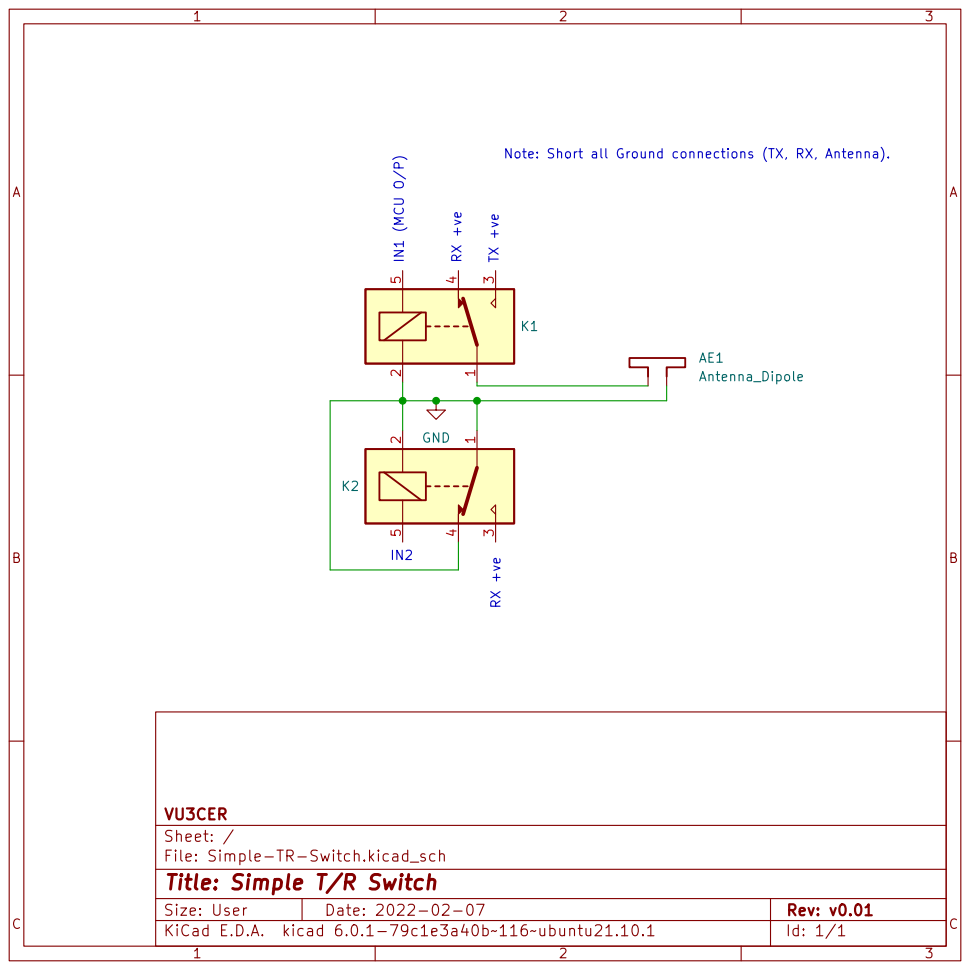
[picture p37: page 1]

3 K2 GND RX +ve TX +ve

File: Simple-TR-Switch.kicad_sch Sheet: / VU3CER

Id: 1/1 Title: Simple T/R Switch

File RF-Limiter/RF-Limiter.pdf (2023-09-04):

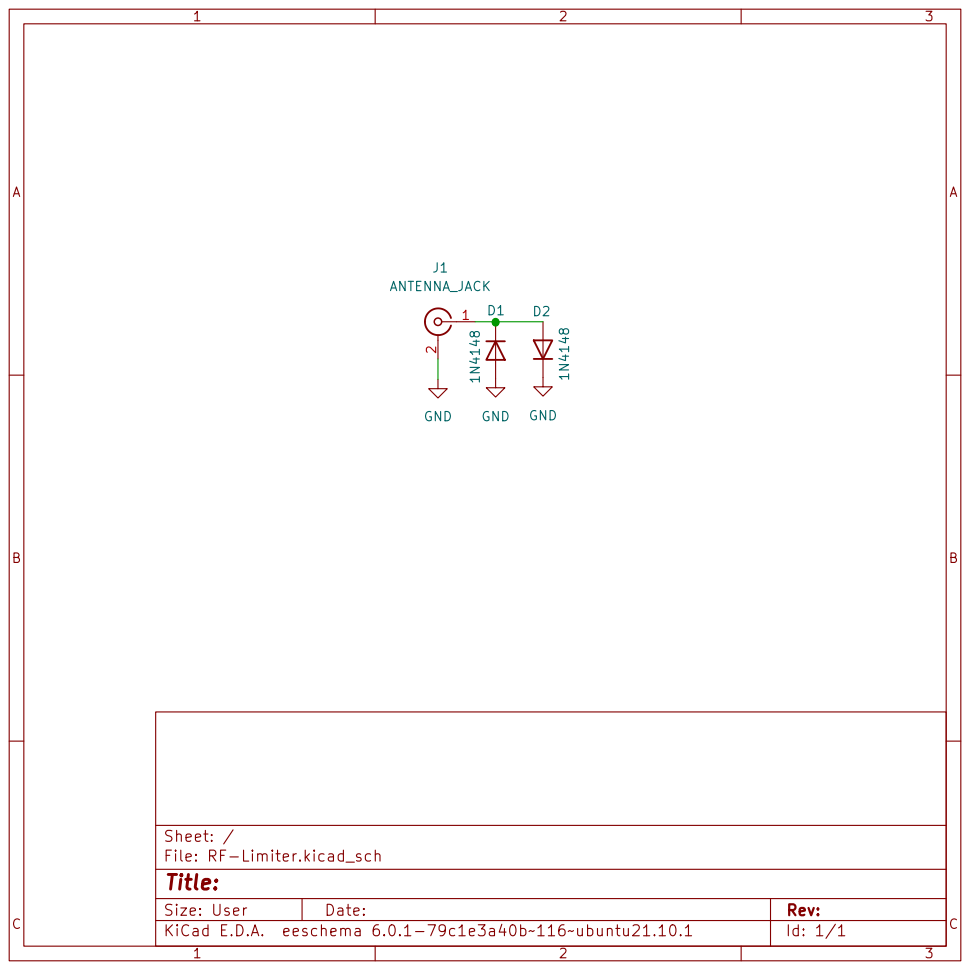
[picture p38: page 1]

File: RF-Limiter.kicad_sch Sheet: /

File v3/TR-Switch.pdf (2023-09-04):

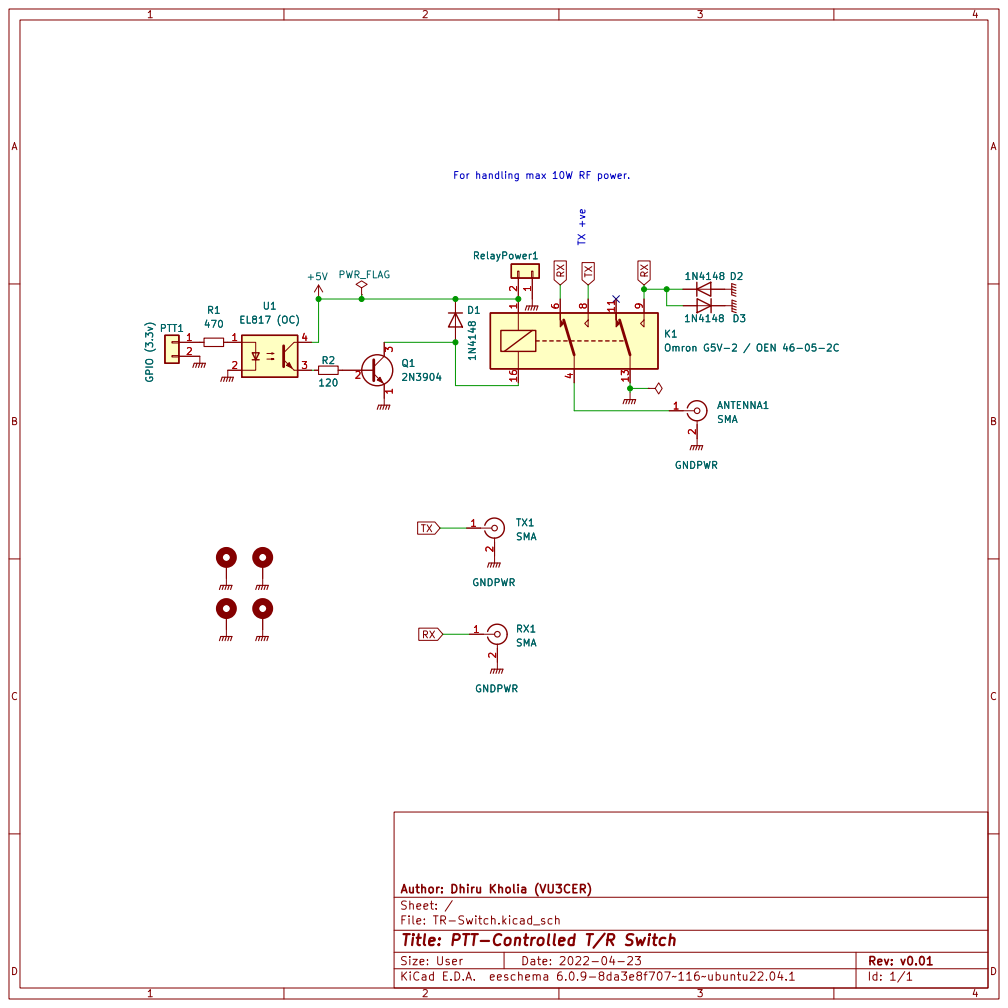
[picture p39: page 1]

For handling max 10W RF power. TX +ve

File: TR-Switch.kicad_sch Sheet: / Author: Dhiru Kholia (VU3CER)

Id: 1/1 Title: PTT-Controlled T/R Switch

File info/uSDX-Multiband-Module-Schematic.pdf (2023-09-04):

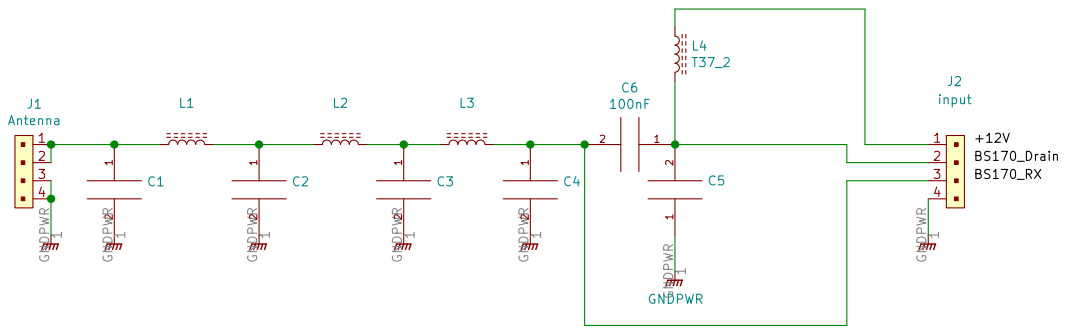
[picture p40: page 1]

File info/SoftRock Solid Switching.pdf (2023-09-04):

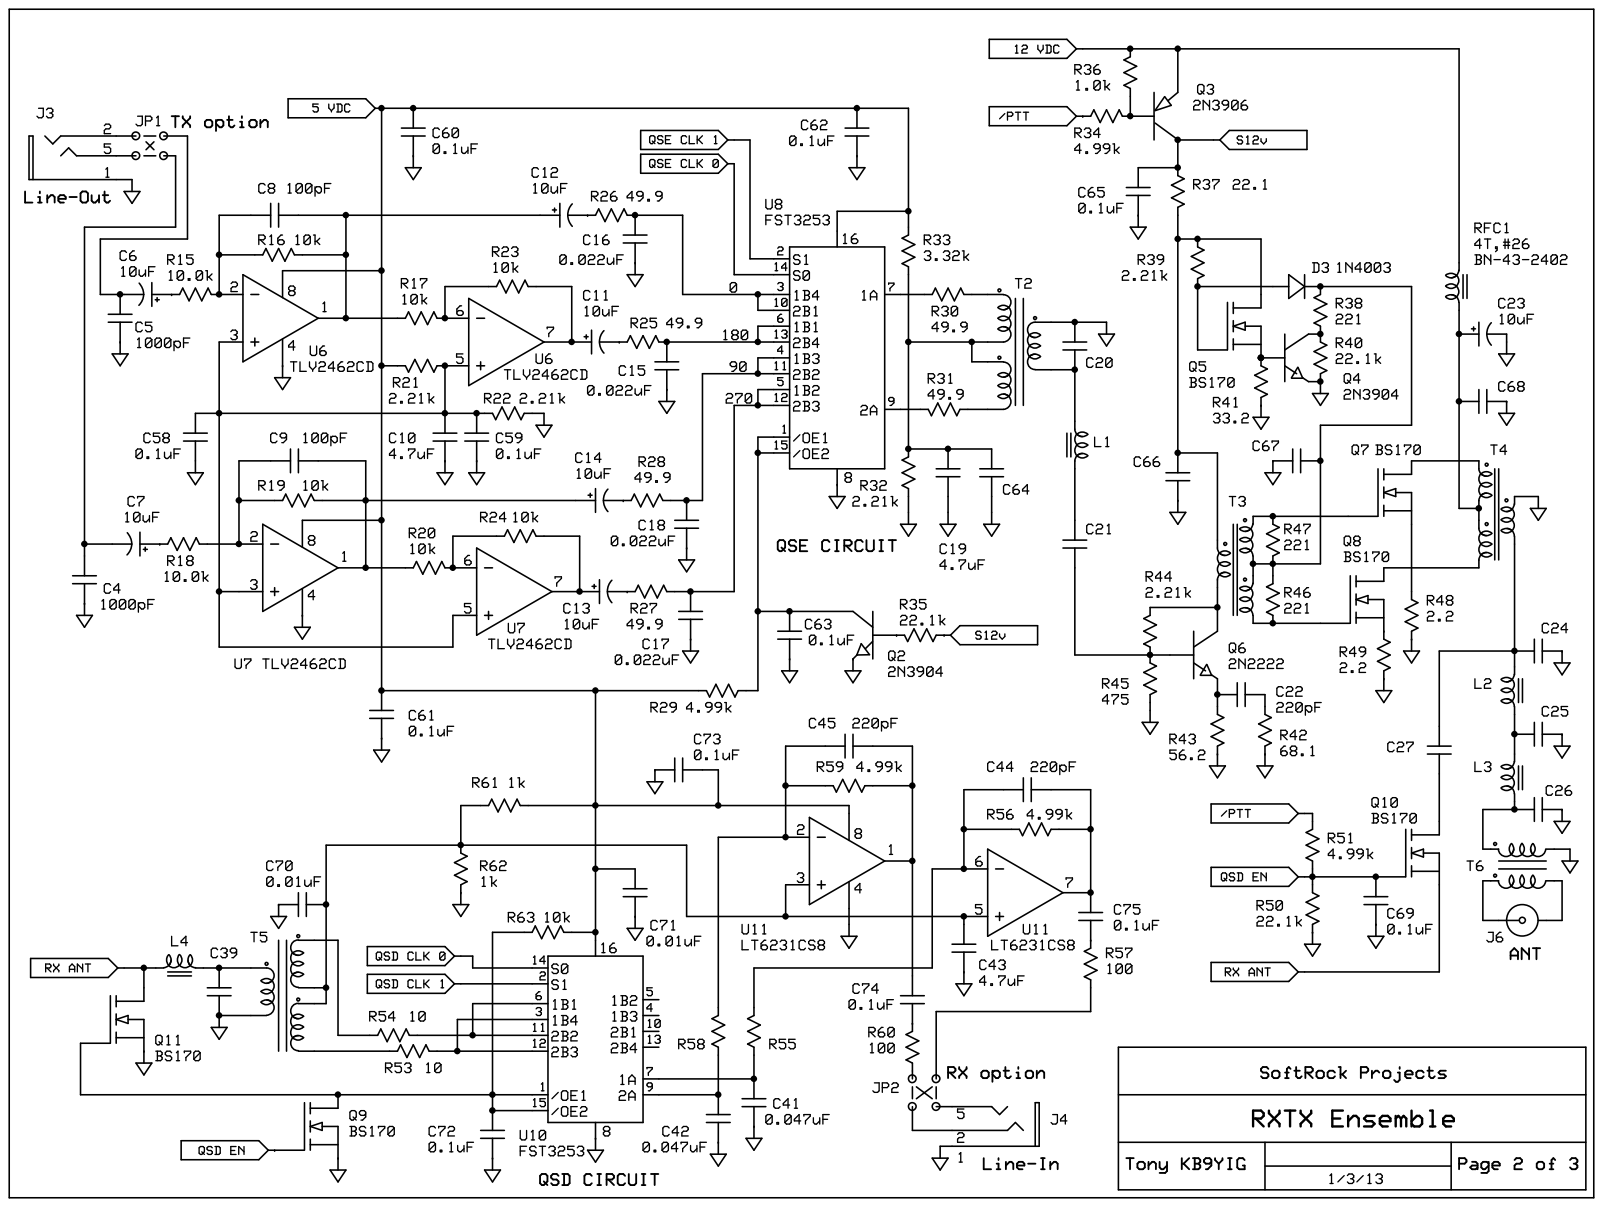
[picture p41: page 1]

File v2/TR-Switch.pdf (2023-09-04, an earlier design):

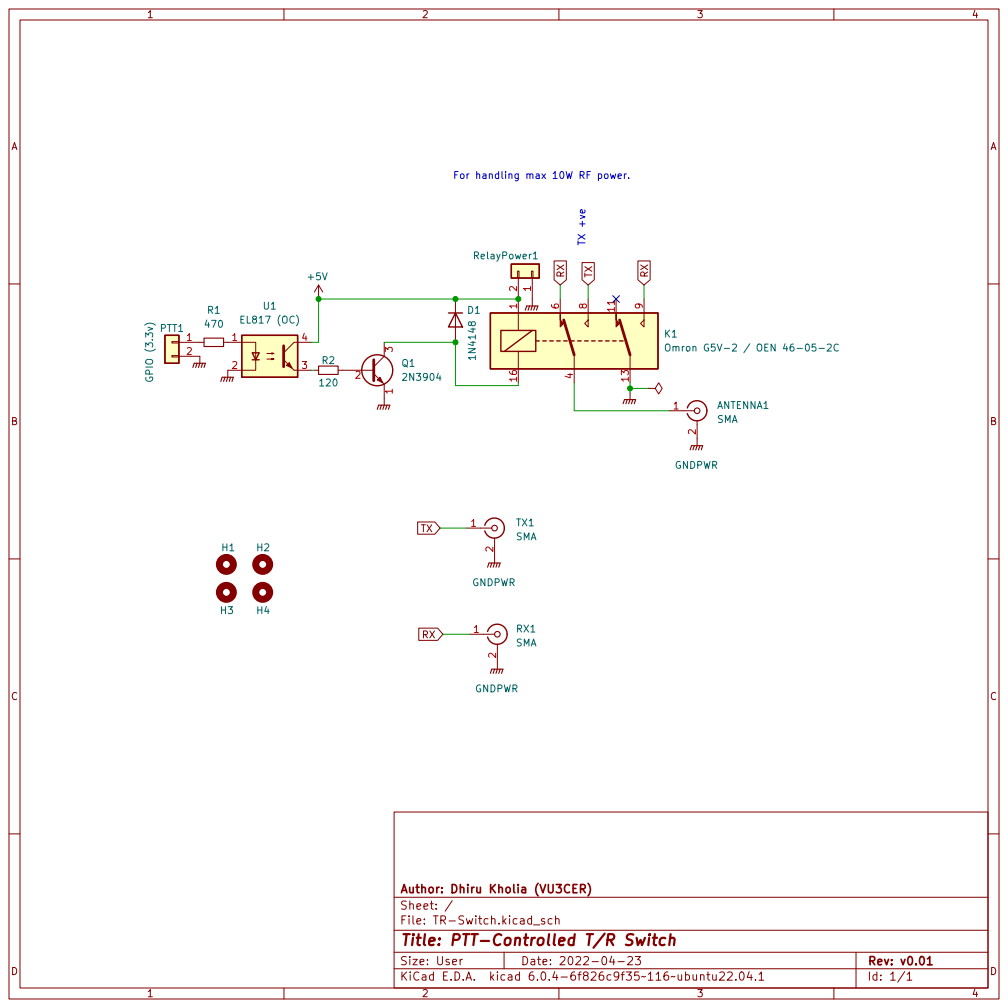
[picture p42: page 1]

For handling max 10W RF power. TX +ve

Id: 1/1 Title: PTT-Controlled T/R Switch

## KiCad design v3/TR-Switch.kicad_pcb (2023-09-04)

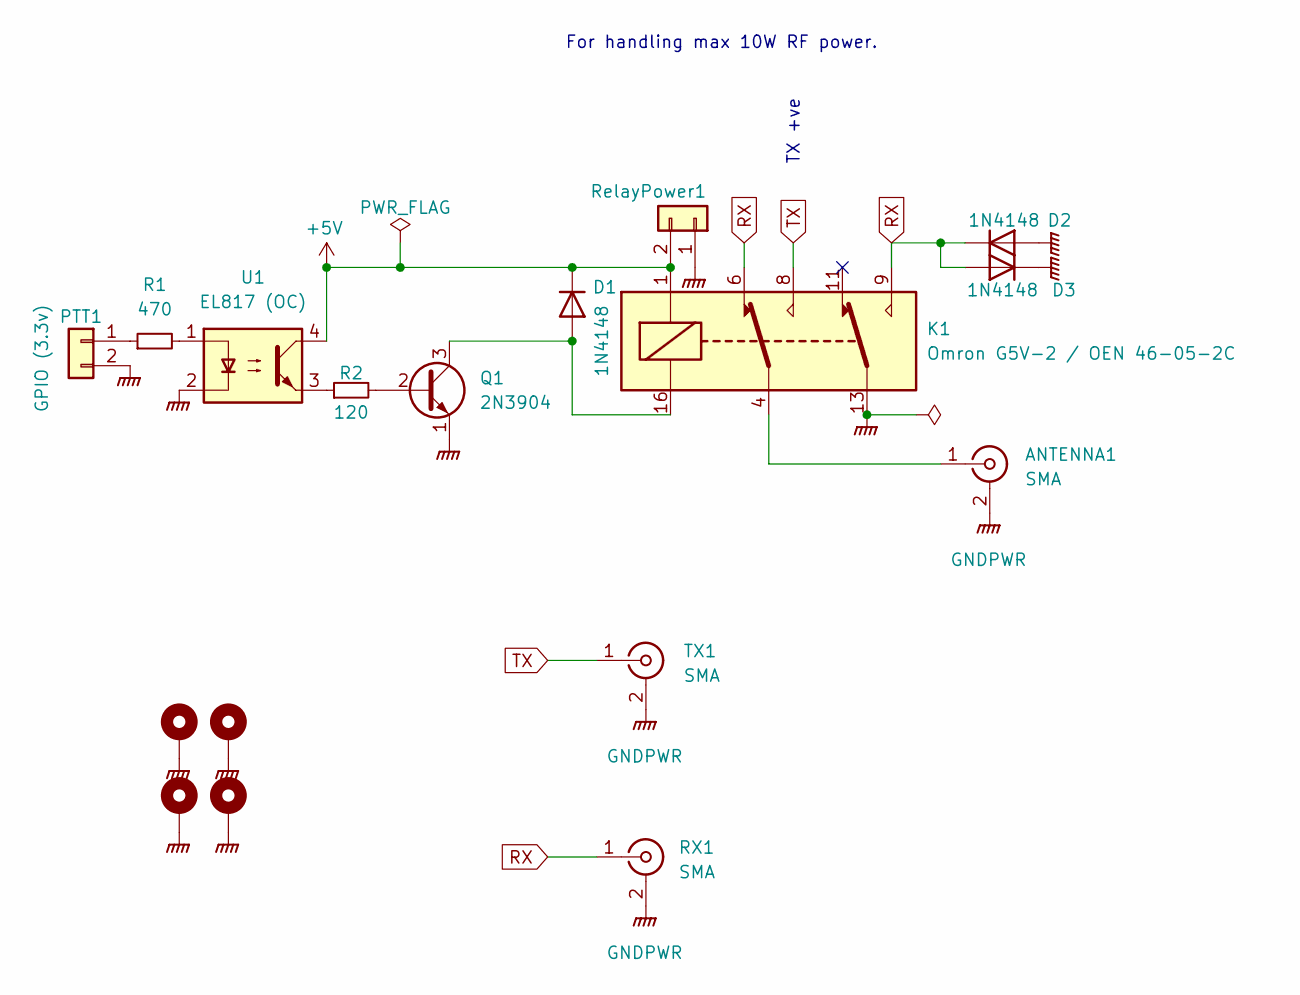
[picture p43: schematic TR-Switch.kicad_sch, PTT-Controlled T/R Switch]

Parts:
ANTENNA1: SMA; SMA_Amphenol_901-144_Vertical
D1, D2, D3: 1N4148; D_DO-35_SOD27_P2.54mm_Vertical_KathodeUp
H1, H2, H3, H4: MountingHole; MountingHole_2.2mm_M2_Pad
K1: Omron G5V-2 / OEN 46-05-2C; Relay_DPDT_Omron_G5V-2
PTT1: GPIO (3.3v); PinHeader_1x02_P2.54mm_Vertical
Q1: 2N3904; PinSocket_1x03_P2.54mm_Vertical
R1: 470; R_1206_3216Metric_Pad1.30x1.75mm_HandSolder
R2: 120; R_1206_3216Metric_Pad1.30x1.75mm_HandSolder
RELAY_POWER1: RelayPower1; PinHeader_1x02_P2.54mm_Vertical
RX1: SMA; SMA_Amphenol_901-144_Vertical
TX1: SMA; SMA_Amphenol_901-144_Vertical
U1: EL817 (OC); DIP-4_W7.62mm

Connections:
+5V: D1.1 (K), K1.1, RELAY_POWER1.2, U1.4
GNDPWR: ANTENNA1.2 (Ext), D2.2 (A), D3.1 (K), H1.1, H2.1, H3.1, H4.1, K1.13, PTT1.2, Q1.1 (E), RELAY_POWER1.1, RX1.2 (Ext), TX1.2 (Ext), U1.2
unnamed: ANTENNA1.1 (In), K1.4
unnamed: D1.2 (A), K1.16, Q1.3 (C)
unnamed: PTT1.1, R1.1
unnamed: Q1.2 (B), R2.2
unnamed: R1.2, U1.1
unnamed: R2.1, U1.3
RX: D2.1 (K), D3.2 (A), K1.6, K1.9, RX1.1 (In)
TX: K1.8, TX1.1 (In)

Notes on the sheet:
TX +ve
For handling max 10W RF power.

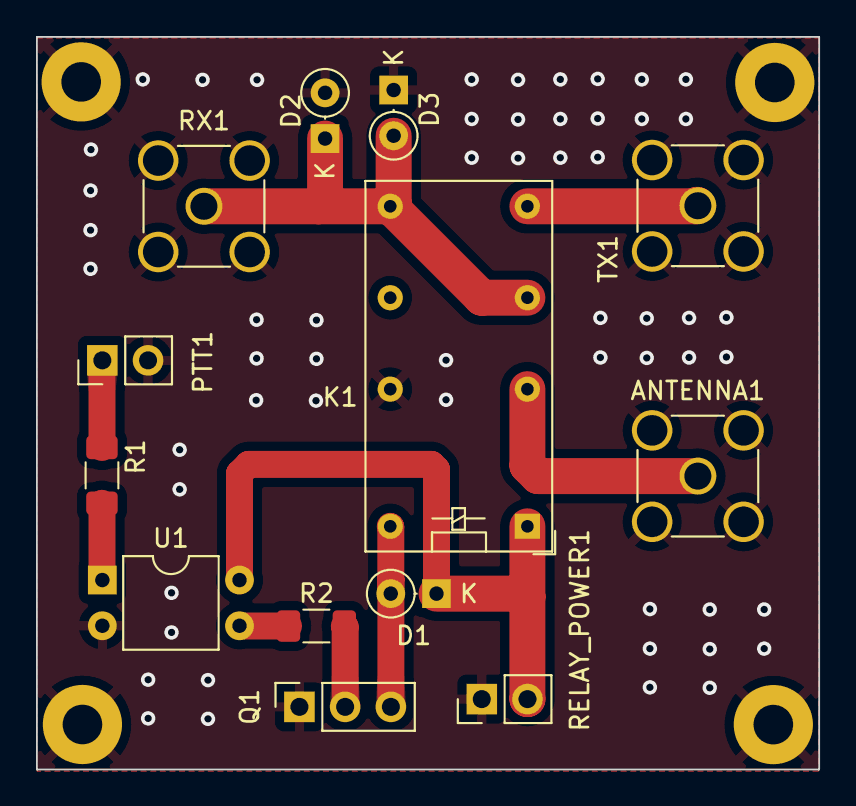
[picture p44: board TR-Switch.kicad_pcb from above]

Board: 2 copper layers, 43.5 x 40.7 mm, 17 parts (0 on the bottom side), 10 nets.

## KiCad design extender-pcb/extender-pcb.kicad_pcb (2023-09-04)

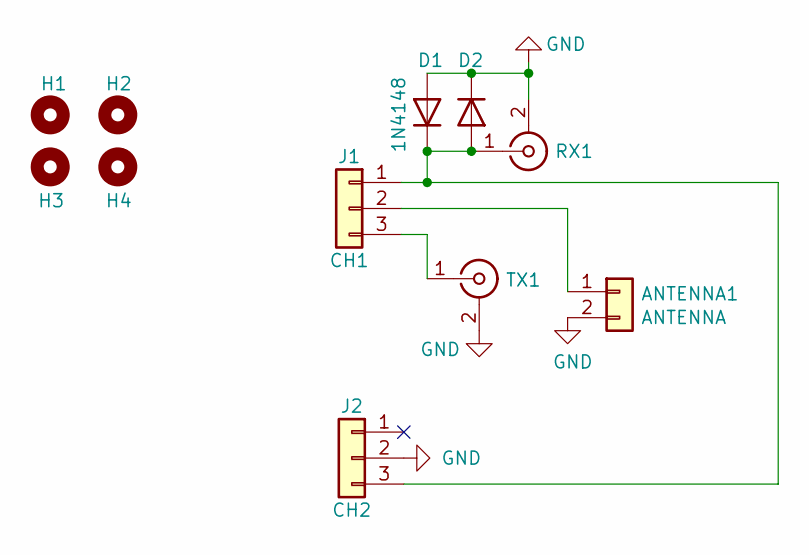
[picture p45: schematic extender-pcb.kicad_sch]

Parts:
ANTENNA1: ANTENNA; TerminalBlock_bornier-2_P5.08mm
D1: 1N4148; D_DO-35_SOD27_P2.54mm_Vertical_KathodeUp
D2: 1N4148; D_DO-35_SOD27_P2.54mm_Vertical_AnodeUp
H1, H2, H3, H4: MountingHole; MountingHole_2.2mm_M2
J1: CH1; TerminalBlock_bornier-3_P5.08mm
J2: CH2; TerminalBlock_bornier-3_P5.08mm
RX1: Conn_Coaxial; SMA_Amphenol_901-144_Vertical
TX1: Conn_Coaxial; SMA_Amphenol_901-144_Vertical

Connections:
GND: ANTENNA1.2, D1.2 (A), D2.1 (K), J2.2, RX1.2 (Ext), TX1.2 (Ext)
unnamed: ANTENNA1.1, J1.2
unnamed: D1.1 (K), D2.2 (A), J1.1, J2.3, RX1.1 (In)
unnamed: J1.3, TX1.1 (In)

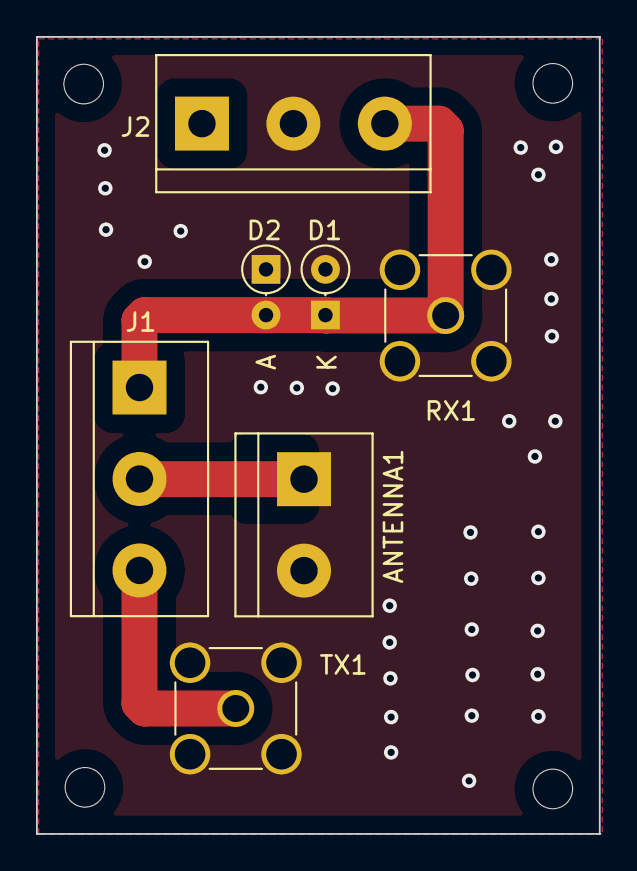
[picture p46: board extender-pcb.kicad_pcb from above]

Board: 2 copper layers, 31.3 x 44.3 mm, 11 parts (0 on the bottom side), 4 nets.
